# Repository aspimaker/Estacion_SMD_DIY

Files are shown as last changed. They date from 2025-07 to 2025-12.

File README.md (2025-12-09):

# Estacion_SMD_DIY
Base de soldadura SMD. Actualmente en desarrollo. No lo construyas todavía.

Utilizando un Arduino Nano, incluye el hardware necesario para calentar y controlar la temperatura usando una NTC y un SSR.
Incluye una pantalla OLED de 0.96", un enconder para moverse por el menú, algunos led y pulsadores.

Está diseñada para utilizar una tira led RGB los estados: frio, calentando, temperatura alcanzada, enfriando...
Puede que lo cambie por una tira WS2812B para simpliicar el diseño y la construcción.

Se podrán crear curvas de temperatura..

Agradezco tu colaboración para ayudarme a con posibles mejoras, corrección de errores, etc...

Gracias y un saludo.

#DIY_SMD_Station
SMD soldering station. Currently under development. Do not build it yet.

Using an Arduino Nano, it includes the necessary hardware for heating and temperature control using an NTC thermistor and an SSR.
It includes a 0.96" OLED screen, an encoder for navigating the menu, some LEDs, and pushbuttons.

It is designed to use an RGB LED strip with the following states: cold, heating, temperature reached, cooling, etc. I may change it to a WS2812B strip to simplify the design and construction.

Temperature curves can be created.

I appreciate your collaboration in helping me with possible improvements, bug fixes, etc.

Thank you and best regards.

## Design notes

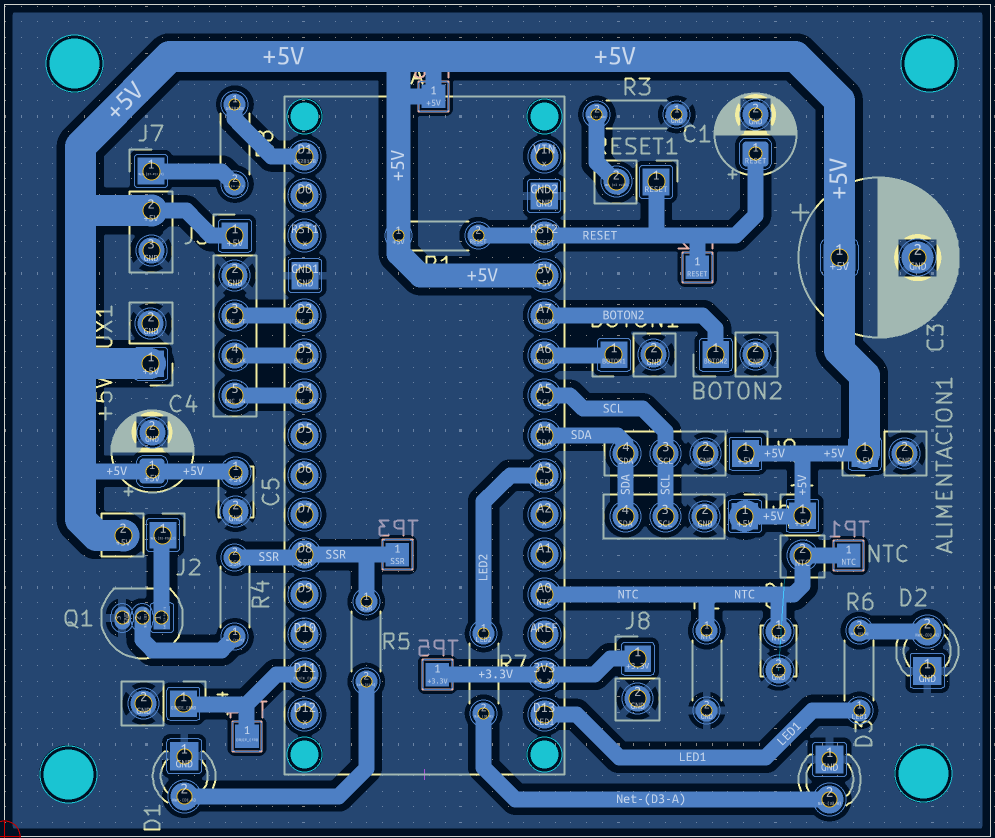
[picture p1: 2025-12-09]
IMAGENES/placa principal pistas.png

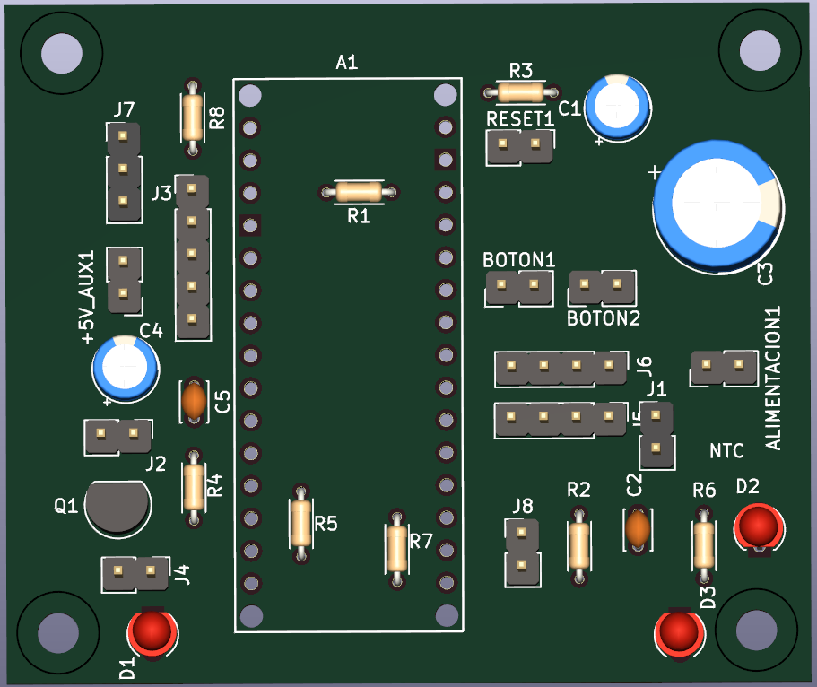
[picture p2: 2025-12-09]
IMAGENES/placa principal 3d.png

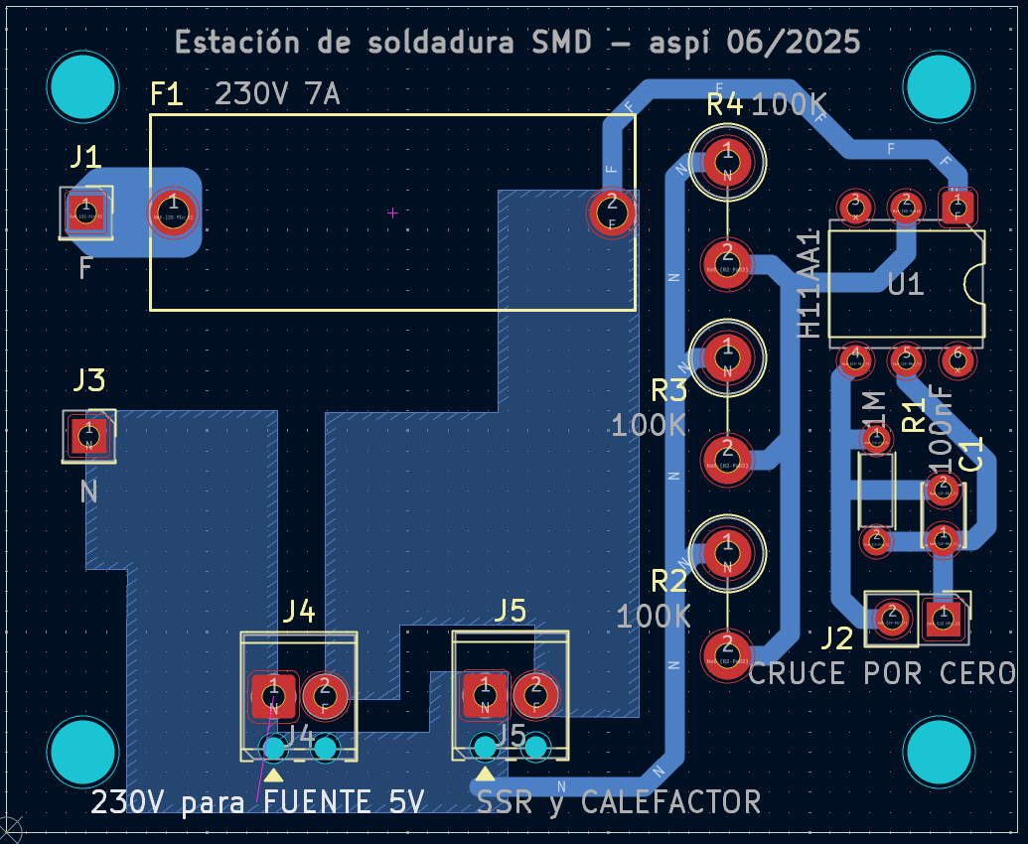
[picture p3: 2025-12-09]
IMAGENES/placa cruce por cero pistas.png

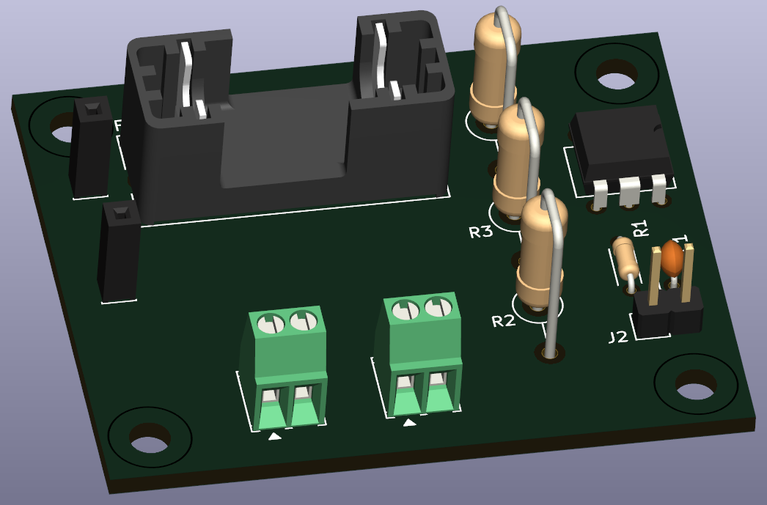
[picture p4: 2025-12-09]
IMAGENES/placa cruce por cero 3d.png

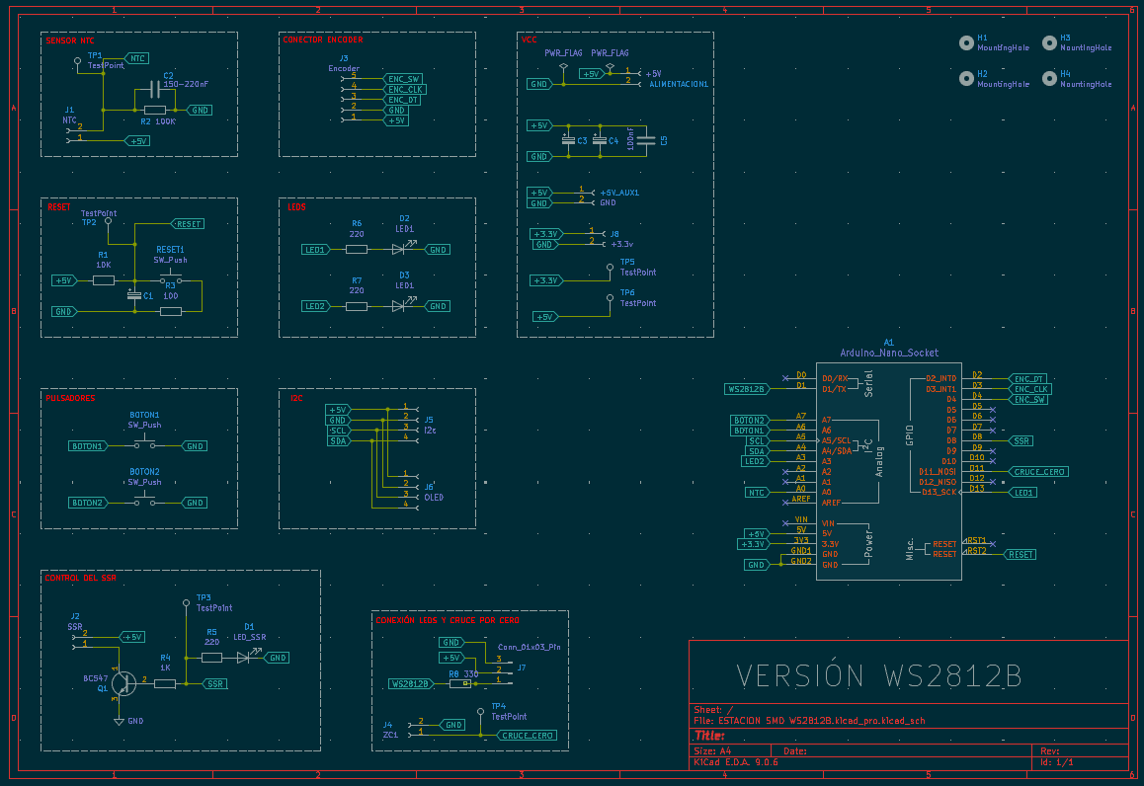
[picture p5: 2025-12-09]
IMAGENES/placa principal esquema.png

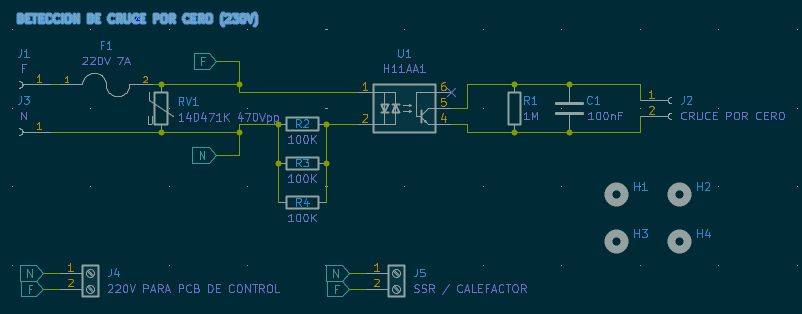
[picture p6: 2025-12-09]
IMAGENES/placa cruce por cero esquema.png

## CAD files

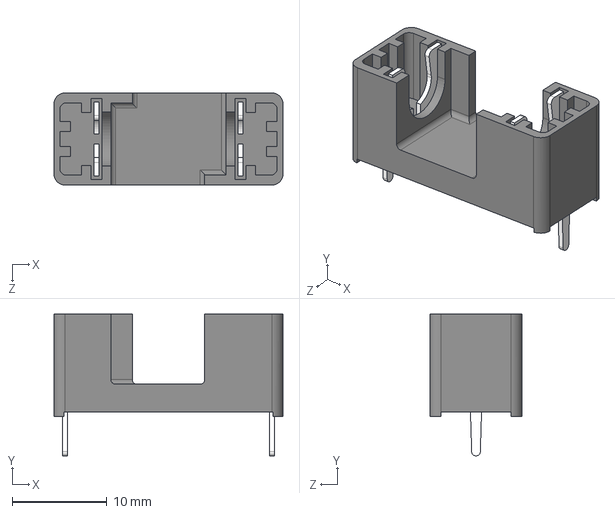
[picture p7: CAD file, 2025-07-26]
CONTROL PRINCIPAL - WS2812B/FUSIBLE 4527--3DModel-STEP-56544.STEP
24.2 x 15.0 x 9.70 mm

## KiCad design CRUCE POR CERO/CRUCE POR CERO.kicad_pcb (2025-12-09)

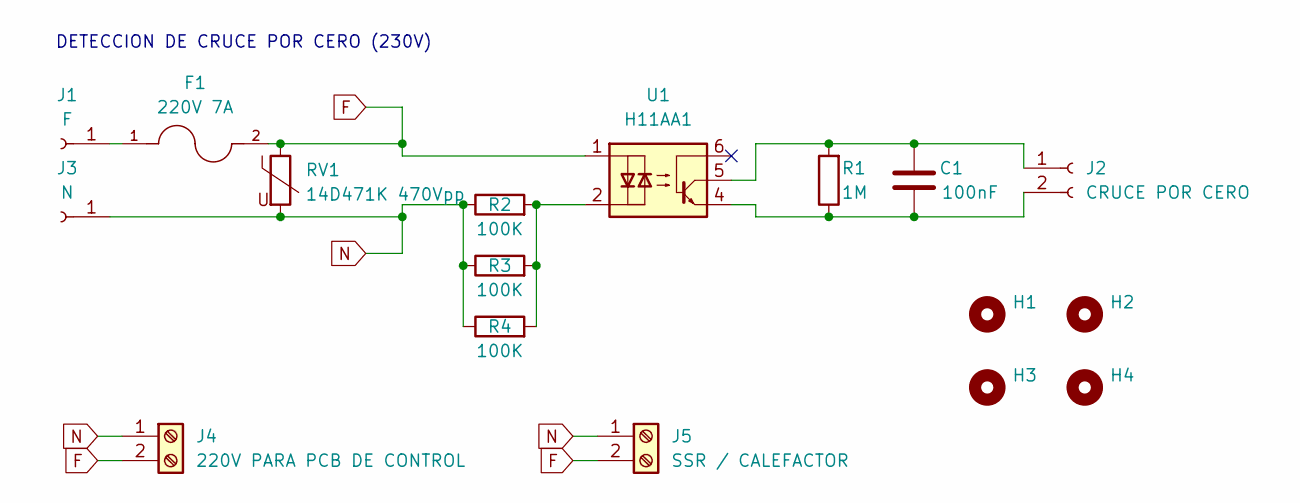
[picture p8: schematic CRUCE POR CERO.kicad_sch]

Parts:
C1: 100nF; C_Disc_D3.0mm_W2.0mm_P2.50mm
F1: 220V 7A; FUSIBLE BLX-A; PARTREV B
H1, H2, H3, H4: MountingHole; MountingHole_3.2mm_M3
J1: F; PinSocket_1x01_P2.54mm_Vertical
J2: CRUCE POR CERO; PinHeader_1x02_P2.54mm_Vertical
J3: N; PinSocket_1x01_P2.54mm_Vertical
J4: 220V PARA PCB DE CONTROL; TerminalBlock_Phoenix_MPT-0,5-2-2.54_1x02_P2.54mm_Horizontal
J5: SSR / CALEFACTOR; TerminalBlock_Phoenix_MPT-0,5-2-2.54_1x02_P2.54mm_Horizontal
R1: 1M; R_Axial_DIN0204_L3.6mm_D1.6mm_P5.08mm_Horizontal
R2, R3, R4: 100K; R_Axial_DIN0411_L9.9mm_D3.6mm_P5.08mm_Vertical
RV1: 14D471K 470Vpp; RV_Disc_D15.5mm_W7.5mm_P7.5mm
U1: H11AA1; DIP-6_W7.62mm

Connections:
F: F1.2, J4.2, J5.2, RV1.1, U1.1
N: J3.1, J4.1, J5.1, R2.1, R3.1, R4.1, RV1.2
unnamed: F1.1, J1.1
unnamed: C1.1, J2.1, R1.2, U1.5
unnamed: C1.2, J2.2, R1.1, U1.4
unnamed: R2.2, R3.2, R4.2, U1.2

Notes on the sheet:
DETECCION DE CRUCE POR CERO (230V)

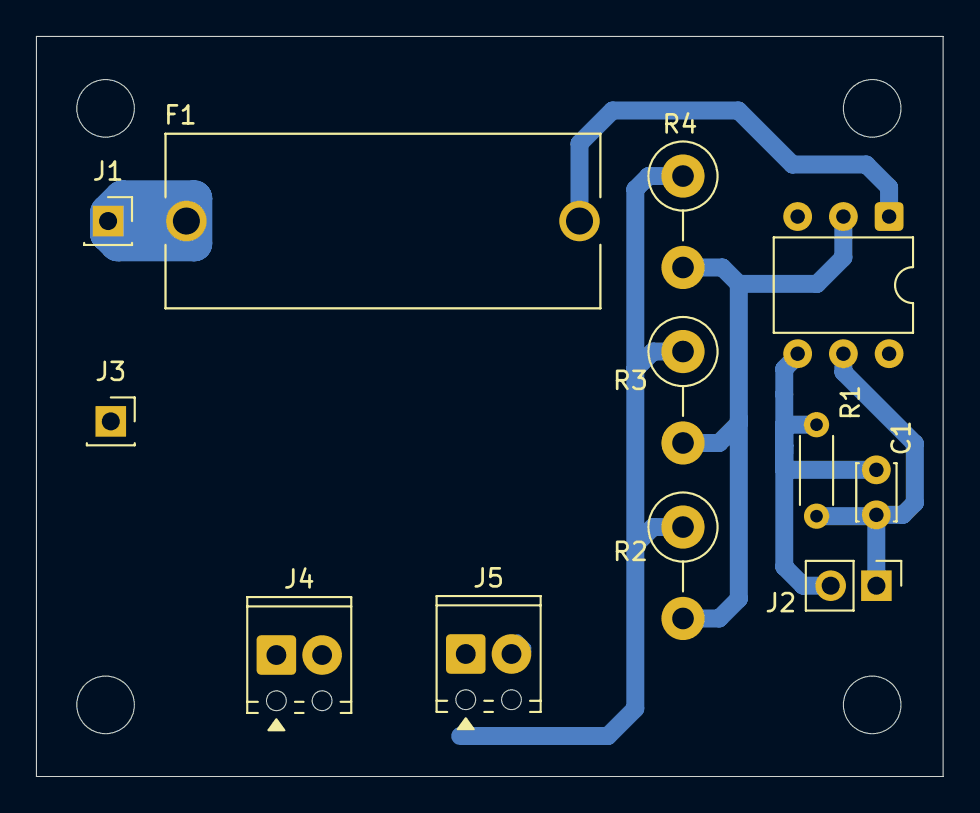
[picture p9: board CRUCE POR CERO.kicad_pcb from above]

Board: 2 copper layers, 50.4 x 41.1 mm, 16 parts (0 on the bottom side), 6 nets.

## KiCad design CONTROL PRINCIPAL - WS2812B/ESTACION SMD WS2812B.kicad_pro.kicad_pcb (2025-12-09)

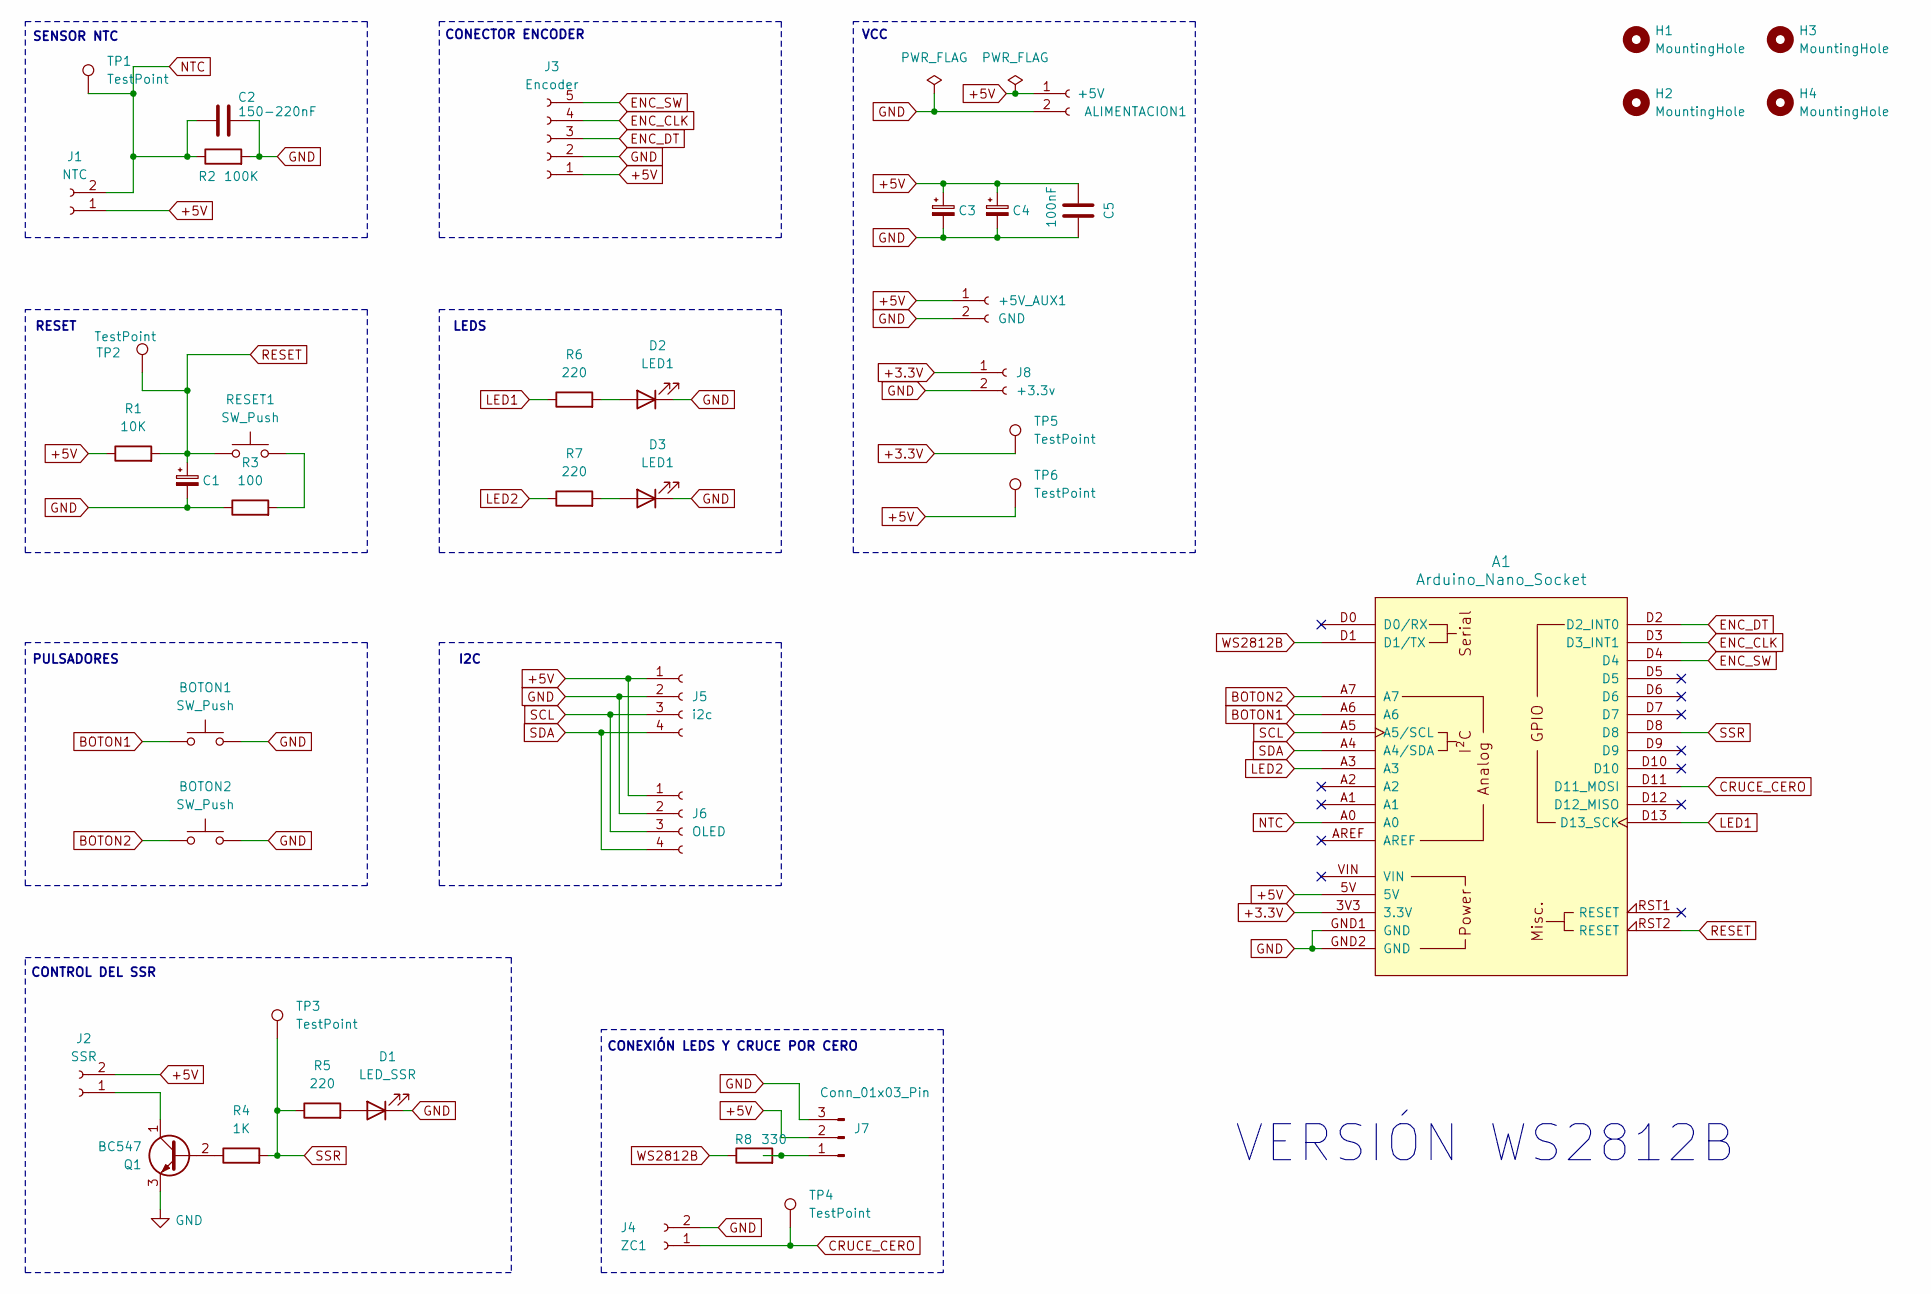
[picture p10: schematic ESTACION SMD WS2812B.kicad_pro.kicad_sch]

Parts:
+5V_AUX1: GND; PinHeader_1x02_P2.54mm_Vertical
A1: Arduino_Nano_Socket
ALIMENTACION1: +5V; PinHeader_1x02_P2.54mm_Vertical
BOTON1, BOTON2: SW_Push; PinHeader_1x02_P2.54mm_Vertical
C1, C4: 10uF/16V; CP_Radial_D5.0mm_P2.50mm
C2: 150-220nF; C_Disc_D3.0mm_W2.0mm_P2.50mm
C3: 1000uF/16V; CP_Radial_D10.0mm_P5.00mm
C5: 100nF; C_Disc_D3.0mm_W2.0mm_P2.50mm
D1: LED_SSR; LED_D3.0mm
D2, D3: LED1; LED_D3.0mm
H1, H2, H3, H4: MountingHole; MountingHole_3.2mm_M3
J1: NTC; PinHeader_1x02_P2.54mm_Vertical
J2: SSR; PinHeader_1x02_P2.54mm_Vertical
J3: Encoder; PinHeader_1x05_P2.54mm_Vertical
J4: ZC1; PinHeader_1x02_P2.54mm_Vertical
J5: i2c; PinHeader_1x04_P2.54mm_Vertical
J6: OLED; PinHeader_1x04_P2.54mm_Vertical
J7: Conn_01x03_Pin; PinHeader_1x03_P2.54mm_Vertical
J8: +3.3v; PinHeader_1x02_P2.54mm_Vertical
Q1: BC547; TO-92_Inline
R1: 10K; R_Axial_DIN0204_L3.6mm_D1.6mm_P5.08mm_Horizontal
R2: 100K; R_Axial_DIN0204_L3.6mm_D1.6mm_P5.08mm_Horizontal
R3: 100; R_Axial_DIN0204_L3.6mm_D1.6mm_P5.08mm_Horizontal
R4: 1K; R_Axial_DIN0204_L3.6mm_D1.6mm_P5.08mm_Horizontal
R5, R6, R7: 220; R_Axial_DIN0204_L3.6mm_D1.6mm_P5.08mm_Horizontal
R8: 330; R_Axial_DIN0204_L3.6mm_D1.6mm_P5.08mm_Horizontal
RESET1: SW_Push; PinHeader_1x02_P2.54mm_Vertical
TP1, TP2, TP3, TP4, TP5, TP6: TestPoint; TestPoint_Pad_1.5x1.5mm

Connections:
+3.3V: A1.3V3 (3.3V), J8.1, TP5.1
+5V: +5V_AUX1.1, A1.5V, ALIMENTACION1.1, C3.1, C4.1, C5.1, J1.1, J2.2, J3.1, J5.1, J6.1, J7.2, R1.1, TP6.1
BOTON1: A1.A6, BOTON1.1
BOTON2: A1.A7, BOTON2.1
CRUCE_CERO: A1.D11 (D11_MOSI), J4.1, TP4.1
ENC_CLK: A1.D3 (D3_INT1), J3.4
ENC_DT: A1.D2 (D2_INT0), J3.3
ENC_SW: A1.D4, J3.5
GND: +5V_AUX1.2, A1.GND1 (GND), A1.GND2 (GND), ALIMENTACION1.2, BOTON1.2, BOTON2.2, C1.2, C2.2, C3.2, C4.2, C5.2, D1.1 (K), D2.1 (K), D3.1 (K), J3.2, J4.2, J5.2, J6.2, J7.3, J8.2, Q1.3 (E), R2.2, R3.1
LED1: A1.D13 (D13_SCK), R6.1
LED2: A1.A3, R7.1
NTC: A1.A0, C2.1, J1.2, R2.1, TP1.1
unnamed: D1.2 (A), R5.2
unnamed: D2.2 (A), R6.2
unnamed: D3.2 (A), R7.2
unnamed: J2.1, Q1.1 (C)
unnamed: J7.1, R8.2
unnamed: Q1.2 (B), R4.1
unnamed: R3.2, RESET1.2
RESET: A1.RST2 (RESET), C1.1, R1.2, RESET1.1, TP2.1
SCL: A1.A5 (A5/SCL), J5.3, J6.3
SDA: A1.A4 (A4/SDA), J5.4, J6.4
SSR: A1.D8, R4.2, R5.1, TP3.1
WS2812B: A1.D1 (D1/TX), R8.1

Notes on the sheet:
CONTROL DEL SSR
I2C
CONECTOR ENCODER
PULSADORES
RESET
SENSOR NTC
CONEXIÓN LEDS Y CRUCE POR CERO
VERSIÓN WS2812B
VCC
LEDS

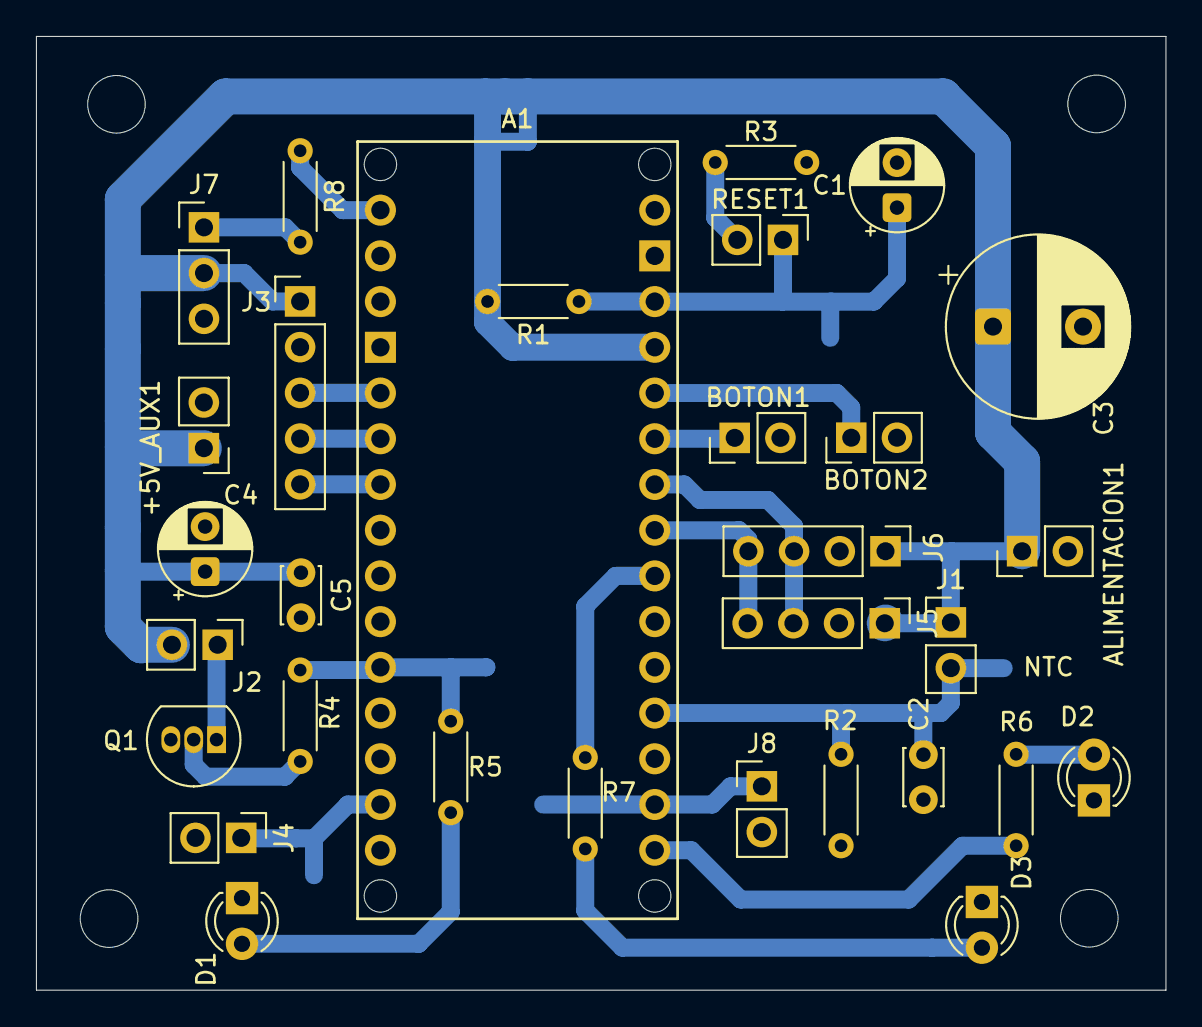
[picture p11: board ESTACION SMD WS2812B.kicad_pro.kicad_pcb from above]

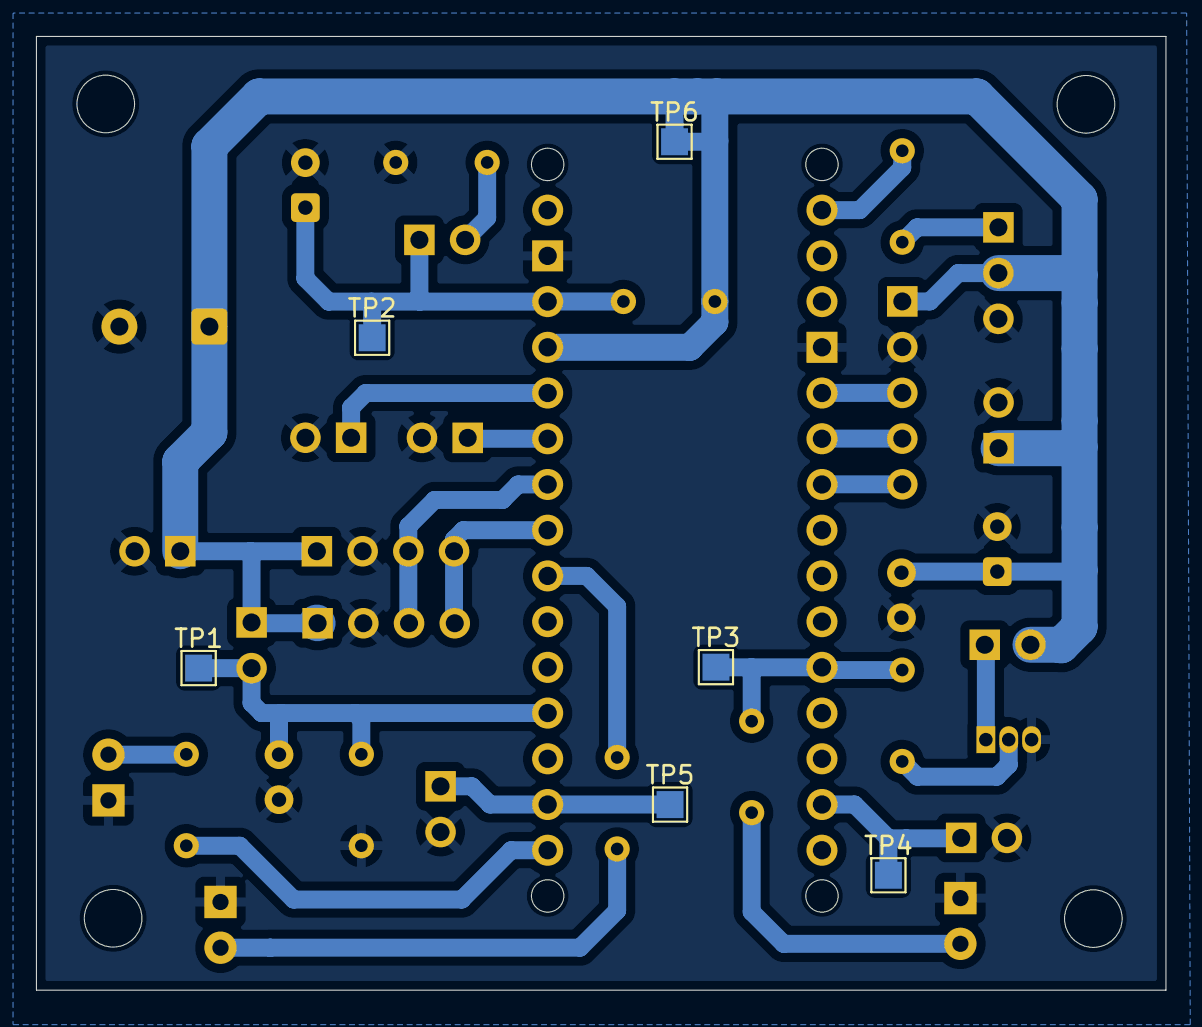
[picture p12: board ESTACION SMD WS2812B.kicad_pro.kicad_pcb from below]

Board: 2 copper layers, 62.8 x 53.0 mm, 41 parts (6 on the bottom side), 24 nets.

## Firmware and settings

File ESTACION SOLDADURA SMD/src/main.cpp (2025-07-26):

#include <Wire.h>
#include <Adafruit_SSD1306.h>
#include <PID_v1.h>
#include <PID_AutoTune_v0.h>
#include <EEPROM.h>
#include <Bounce2.h>

// Configuración OLED
#define OLED_ANCHO 128
#define OLED_ALTO 64
Adafruit_SSD1306 oled(OLED_ANCHO, OLED_ALTO, &Wire, -1);

// Pines
#define SSR_PIN  8
#define NTC_PIN A0
#define ENCODER_CLK_PIN 3
#define ENCODER_DT_PIN 2
#define ENCODER_SW_PIN 4
#define LED_R_PIN  5
#define LED_G_PIN  9
#define LED_B_PIN 10
#define ZC_PIN 11

// Constantes de control
#define HISTERESIS_ON 5    // °C diferencia para encender
#define HISTERESIS_OFF 2   // °C diferencia para apagar
#define TEMP_MAX 300       // Límite térmico absoluto
#define TIMEOUT_MIN 30     // Apagado automático (minutos)
#define DEBOUNCE_TIME 25   // ms para debounce

// Configuración NTC
#define ResistenciaSerieNTC 100000.0
#define NUM_LECTURAS 10
#define BETA 3950.0        // Coeficiente beta del NTC
#define TEMP_NOMINAL 25    // Temperatura nominal (para cálculo NTC)
#define RESISTENCIA_NOMINAL 100000 // Resistencia a temp nominal

// EEPROM
#define EEPROM_ADDR_SETPOINT 0
#define EEPROM_ADDR_PID 10

// Instancias Bounce2
Bounce debouncerEncoderCLK = Bounce();
Bounce debouncerEncoderSW = Bounce();

struct PIDParams {
    double Kp, Ki, Kd;
    byte checksum;
};

// Variables de estado
int setpoint = 150;
bool calentando = false;
unsigned long ultimaActualizacion = 0;
volatile bool crucePorCeroDetectado = false;

// Variables PID
double temperaturaActual = 0, salidaPID = 0, temperaturaObjetivo = 150;
PID controladorPID(&temperaturaActual, &salidaPID, &temperaturaObjetivo, 30, 5, 50, DIRECT);

// Auto-tuning
PID_ATune autotune(&temperaturaActual, &salidaPID);
bool autoTuning = false;
unsigned long tiempoAutoTune = 0;


void guardarPID() {
    PIDParams params = {controladorPID.GetKp(), controladorPID.GetKi(), controladorPID.GetKd(), 0};
    params.checksum = (byte)(params.Kp + params.Ki + params.Kd);
    EEPROM.put(EEPROM_ADDR_PID, params);
}

PIDParams cargarValidarPIDParams() {
    PIDParams params;
    EEPROM.get(EEPROM_ADDR_PID, params);
    
    bool eepromCorrupta = false;
    
    if (isnan(params.Kp) || isnan(params.Ki) || isnan(params.Kd)) {
        eepromCorrupta = true;
    }
    
    if (params.Kp < 1 || params.Kp > 100 ||
        params.Ki < 0 || params.Ki > 10 ||
        params.Kd < 0 || params.Kd > 100) {
        eepromCorrupta = true;
    }
    
    byte checksumCalculado = (byte)(params.Kp + params.Ki + params.Kd);
    if (params.checksum != checksumCalculado) {
        eepromCorrupta = true;
    }
    
    if (eepromCorrupta) {
        params = {15.0, 0.5, 10.0, (byte)(15.0 + 0.5 + 10.0)};
        EEPROM.put(EEPROM_ADDR_PID, params);
    }
    
    return params;
}

void tiraLED_ROJO() { analogWrite(LED_R_PIN, 255); analogWrite(LED_G_PIN, 0); analogWrite(LED_B_PIN, 0); }
void tiraLED_VERDE() { analogWrite(LED_R_PIN, 0); analogWrite(LED_G_PIN, 255); analogWrite(LED_B_PIN, 0); }
void tiraLED_AZUL() { analogWrite(LED_R_PIN, 0); analogWrite(LED_G_PIN, 0); analogWrite(LED_B_PIN, 255); }
void tiraLED_AMARILLO() { analogWrite(LED_R_PIN, 255); analogWrite(LED_G_PIN, 255); analogWrite(LED_B_PIN, 0); }
void tiraLED_BLANCO() { analogWrite(LED_R_PIN, 255); analogWrite(LED_G_PIN, 255); analogWrite(LED_B_PIN, 255); }

void emergenciaTermica(const char* motivo) {
    digitalWrite(SSR_PIN, LOW);
    tiraLED_ROJO();
    oled.clearDisplay();
    oled.setCursor(0, 0);
    oled.println(motivo);
    oled.print(F("Temp: ")); oled.print(temperaturaActual); oled.println(F("°C"));
    oled.println(F("Reiniciar equipo"));
    oled.display();
    
    while(1) {
        digitalWrite(LED_R_PIN, !digitalRead(LED_R_PIN));
        delay(500);
    }
}

void mostrarError(const char* mensaje, bool bloqueante) {
    oled.clearDisplay();
    oled.setCursor(0, 0);
    oled.println(mensaje);
    oled.print(F("Temp: ")); oled.print(temperaturaActual); oled.println(F("°C"));
    oled.display();
    
    if (bloqueante) {
        while(1) {
            tiraLED_ROJO();
            delay(500);
            tiraLED_BLANCO();
            delay(500);
        }
    }
}

void iniciarAutoTuning() {
    if(temperaturaActual < 100) {
        mostrarError("Temp <100°C", false);
        return;
    }
    autoTuning = true;
    tiempoAutoTune = millis();

    autotune.Cancel();
    autotune.SetNoiseBand(2.0);
    autotune.SetOutputStep(100);
    autotune.SetLookbackSec(10);

    tiraLED_AMARILLO();
}

void finalizarAutoTuning() {
    autoTuning = false;
    controladorPID.SetTunings(autotune.GetKp(), autotune.GetKi(), autotune.GetKd());
    guardarPID();

    tiraLED_ROJO();
}

void abortarAutoTuning() {
    autoTuning = false;
    emergenciaTermica("FALLO AUTO-TUNE");
}

void ejecutarControlSSR() {
  static unsigned long ultimoCiclo = 0;
  unsigned long ahora = millis();

  if (ahora - ultimoCiclo < 10) return; // Protección contra rebotes
  ultimoCiclo = ahora;
  
  if (salidaPID > 10 && calentando && !autoTuning) {
      unsigned int tiempoON = constrain(map(salidaPID, 0, 255, 1000, 8000), 1000, 8000);
      digitalWrite(SSR_PIN, HIGH);
      delayMicroseconds(tiempoON);
      digitalWrite(SSR_PIN, LOW);
  }

  crucePorCeroDetectado = false;
}

float leerTemperaturaNTC(int pin) {
    int adc = analogRead(pin);
    if (adc < 1 || adc > 1023) return NAN;

    float resistencia = ResistenciaSerieNTC * ((1023.0 / adc) - 1.0);
    float tempK = 1.0 / (1.0/298.15 + (1.0/BETA) * log(resistencia/RESISTENCIA_NOMINAL));
    return tempK - 273.15;
}

float leerTemperaturaFiltrada() {
    float suma = 0;
    int lecturasValidas = 0;

    for (int i = 0; i < NUM_LECTURAS; i++) {
        float t = leerTemperaturaNTC(NTC_PIN);
        if (!isnan(t) && t > -50 && t < TEMP_MAX) {
            suma += t;
            lecturasValidas++;
        }
        delay(5);
    }
    
    if (lecturasValidas == 0) return NAN;
    return suma / lecturasValidas;
}

bool validarTemperatura(float temp, bool bloqueante) {
    if (isnan(temp)) {
        mostrarError("Error: Sensor NTC", bloqueante);
        return false;
    }
    if (temp < 10 || temp > TEMP_MAX) {
        mostrarError("Ajuste NTC!", bloqueante);
        return false;
    }
    return true;
}

void verificarEEPROM() {
    static unsigned long ultimaVerificacion = 0;
    const unsigned long intervalo = 3600000; // 1 hora
    
    if (millis() - ultimaVerificacion > intervalo) {
        PIDParams params;
        EEPROM.get(EEPROM_ADDR_PID, params);
        byte checksum = (byte)(params.Kp + params.Ki + params.Kd);

        if (checksum != params.checksum) {
            emergenciaTermica("ERROR EEPROM");
        }
        ultimaVerificacion = millis();
    }
}

void controlTemperatura() {
    static unsigned long ultimoSobretemperatura = 0;

    if (isnan(temperaturaActual)) {
        emergenciaTermica("FALLO SENSOR");
    }
    else if (temperaturaActual < -50) {
        emergenciaTermica("TEMPERATURA BAJA");
    }
    else if (temperaturaActual >= TEMP_MAX) {
        if(millis() - ultimoSobretemperatura > 5000) {
            emergenciaTermica("SOBRETEMPERATURA");
        }
        ultimoSobretemperatura = millis();
    }
}

void actualizarLEDs() {
    if (autoTuning) {
        tiraLED_AMARILLO();
    } else if (calentando) {
        tiraLED_ROJO();
    } else {
        tiraLED_AZUL();
    }
}

void actualizarEncoder() {
    static int ultimoEstadoDT = HIGH;
    static unsigned long ultimoCambio = 0;
    
    debouncerEncoderCLK.update();
    debouncerEncoderSW.update();
    
    int estadoCLK = debouncerEncoderCLK.read();
    int estadoDT = digitalRead(ENCODER_DT_PIN);
    
    if (estadoCLK != ultimoEstadoDT) {
        if (millis() - ultimoCambio > 50) {
            int cambio = (estadoDT == estadoCLK) ? -5 : 5;
            setpoint = constrain(setpoint + cambio, 25, 250);
            
            if (setpoint != temperaturaObjetivo) {
                temperaturaObjetivo = setpoint;
                EEPROM.update(EEPROM_ADDR_SETPOINT, setpoint);
            }
            ultimoCambio = millis();
        }
    }
    ultimoEstadoDT = estadoCLK;

    if (debouncerEncoderSW.fell()) {
        calentando = !calentando;
        tiraLED_BLANCO();
        delay(100);
        actualizarLEDs();
    }
    
    if (debouncerEncoderSW.duration() > 3000 && !autoTuning && temperaturaActual > 100) {
        iniciarAutoTuning();
    }
}

void manejarControlTemperatura() {
    static unsigned long ultimoControl = 0;
    const unsigned long intervaloControl = 100;
    
    float diferencia = temperaturaObjetivo - temperaturaActual;
    
    if (!autoTuning) {
        if (diferencia > HISTERESIS_ON) {
            calentando = true;
        } else if (diferencia < -HISTERESIS_OFF) {
            calentando = false;
        }
    }

    if (millis() - ultimoControl >= intervaloControl) {
        if (autoTuning) {
            if (millis() - tiempoAutoTune > 300000) { // 5 minutos máximo
                abortarAutoTuning();
            }
            if (autotune.Runtime() != 0) {
                finalizarAutoTuning();
            }
        } else {
            controladorPID.Compute();
        }
        ultimoControl = millis();
    }
    
    if (crucePorCeroDetectado && calentando && !autoTuning) {
        ejecutarControlSSR();
    }
}

void dibujarGrafica(int tempActual, int tempObjetivo) {
    static int valores[64];
    static int index = 0;
    static int lastYSetpoint = -1;
    
    int ySetpoint = map(tempObjetivo, 0, TEMP_MAX, OLED_ALTO-1, 15);
    
    if(ySetpoint != lastYSetpoint) {
        oled.drawLine(0, lastYSetpoint, OLED_ANCHO-1, lastYSetpoint, SSD1306_BLACK);
        oled.drawLine(0, ySetpoint, OLED_ANCHO-1, ySetpoint, SSD1306_WHITE);
        lastYSetpoint = ySetpoint;
    }
    
    oled.drawLine(index*2, OLED_ALTO-1, index*2, 15, SSD1306_BLACK);
    valores[index] = map(tempActual, 0, TEMP_MAX, OLED_ALTO-1, 15);
    oled.drawLine(index*2, OLED_ALTO-1, index*2, valores[index], SSD1306_WHITE);
    
    index = (index + 1) % 64;
}

void actualizarPantalla() {
    static unsigned long ultimoRefresh = 0;
    if (millis() - ultimoRefresh < 500) return;
    ultimoRefresh = millis();

    oled.clearDisplay();
    
    // Header
    oled.setCursor(0, 0);
    oled.print(F("ESTACION SMD "));
    oled.print(autoTuning ? F("[AT]") : calentando ? F("[ON]") : F("[OFF]"));
    
    // Temperaturas
    oled.setCursor(0, 15);
    oled.print(F("Actual: ")); 
    oled.print(temperaturaActual, 1); 
    oled.print(F("°C"));
    
    oled.setCursor(0, 25);
    oled.print(F("Objetivo: ")); 
    oled.print(setpoint); 
    oled.print(F("°C"));

    // PID
    oled.setCursor(0, 35);
    oled.print(F("PID: "));
    oled.print(controladorPID.GetKp(), 1); oled.print(F(","));
    oled.print(controladorPID.GetKi(), 1); oled.print(F(","));
    oled.print(controladorPID.GetKd(), 1);

    // Gráfico
    dibujarGrafica(temperaturaActual, setpoint);
    
    // Footer
    oled.setCursor(0, 55);
    oled.print(F("Gira+Hold: AT"));
    oled.display();
}

  void detectarCrucePorZC() {
    static unsigned long ultimaInterrupcion = 0;
    unsigned long ahora = millis();
    
    // Filtro debounce para interrupciones
    if (ahora - ultimaInterrupcion > 2) {
        crucePorCeroDetectado = true;
        ultimaInterrupcion = ahora;
    }
}

void setup() {
    Serial.begin(9600);
    Wire.begin();

    if (!oled.begin(SSD1306_SWITCHCAPVCC, 0x3C)) {
        while(1); // Fallo crítico
    }

    oled.clearDisplay();
    oled.setTextSize(1);
    oled.setTextColor(SSD1306_WHITE);
    oled.setCursor(0, 0);
    oled.println(F("     ESTACION DE"));
    oled.println(F("      SOLDADURA"));
    oled.println(F(" "));
    oled.println(F("   aspimaker 06/2025"));
    oled.display();
    delay(2000);

    pinMode(SSR_PIN, OUTPUT);
    digitalWrite(SSR_PIN, LOW);  // por seguridad apagamos el SSR

    pinMode(LED_R_PIN, OUTPUT);
    pinMode(LED_G_PIN, OUTPUT);
    pinMode(LED_B_PIN, OUTPUT);
    pinMode(ZC_PIN, INPUT_PULLUP);

    debouncerEncoderCLK.attach(ENCODER_CLK_PIN, INPUT_PULLUP);
    debouncerEncoderCLK.interval(DEBOUNCE_TIME);

    debouncerEncoderSW.attach(ENCODER_SW_PIN, INPUT_PULLUP);
    debouncerEncoderSW.interval(DEBOUNCE_TIME);

    attachInterrupt(digitalPinToInterrupt(ZC_PIN), detectarCrucePorZC, FALLING);

    PIDParams params = cargarValidarPIDParams();
    controladorPID.SetTunings(params.Kp, params.Ki, params.Kd);
    
    byte valorEEPROM = EEPROM.read(EEPROM_ADDR_SETPOINT);
    if (valorEEPROM >= 25 && valorEEPROM <= 250) {
        setpoint = valorEEPROM;
        temperaturaObjetivo = setpoint;
    }

    controladorPID.SetMode(AUTOMATIC);
    controladorPID.SetSampleTime(50);
    controladorPID.SetOutputLimits(0, 255);

    float temp = leerTemperaturaFiltrada();
    if (!validarTemperatura(temp, true)) {
        emergenciaTermica("FALLO SENSOR");
    }
}

void loop() {

    static unsigned long ultimoLoop = millis();
    static unsigned long ultimoControl = millis();
    
    // Verificación del bucle principal
    if (millis() - ultimoLoop > 5000) {
        emergenciaTermica("FALLO_LOOP");
    }
    ultimoLoop = millis();

    // Lectura de temperatura
    temperaturaActual = leerTemperaturaFiltrada();
    if (!validarTemperatura(temperaturaActual, false)) {
        return;
    }

    // Control principal
    verificarEEPROM();

    controlTemperatura();

    actualizarEncoder();

    manejarControlTemperatura();

    actualizarPantalla();

    actualizarLEDs();
}

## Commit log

2025-07-26 Código para Arduino Nano
2025-07-26 Esquema y PCB principal, en Kidad
    [ESTACION SMD.kicad_pcb, ESTACION SMD.kicad_sch, FUSIBLE 4527--3DModel-STEP-56544.STEP]
2025-07-26 Esquema y PCB de la detección de paso por cero
    [CRUCE POR CERO.kicad_pcb, CRUCE POR CERO.kicad_sch, FUSIBLE 4527--3DModel-STEP-56544.STEP]
2025-12-09 Enhance README with project details and acknowledgments
    Updated README to include additional information in both Spanish and English about the SMD soldering station project, its current development status, and hardware details.
2025-12-09 actualización
    [CRUCE POR CERO.kicad_pcb, CRUCE POR CERO.kicad_sch]
